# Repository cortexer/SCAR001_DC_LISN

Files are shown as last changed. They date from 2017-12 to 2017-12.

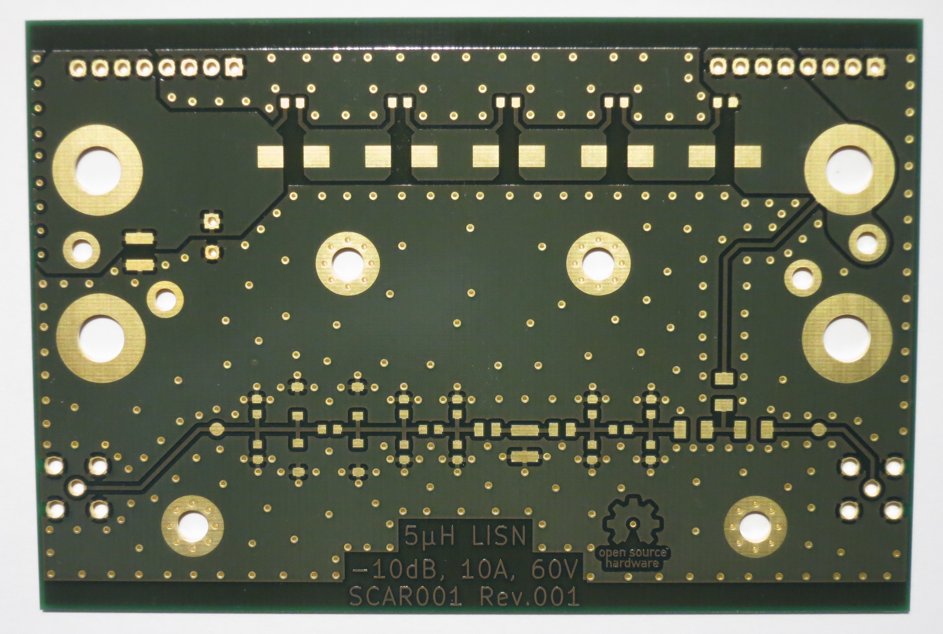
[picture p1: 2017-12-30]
06_Images/RawPCB.jpg

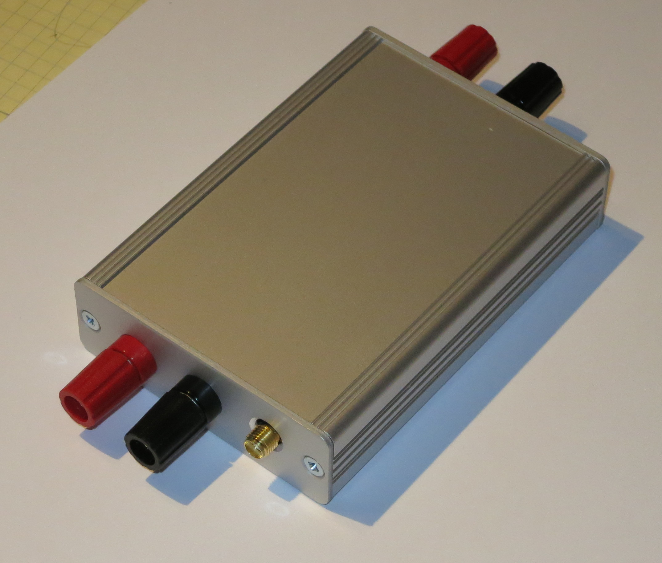
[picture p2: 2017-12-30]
06_Images/LISN_finished.jpg

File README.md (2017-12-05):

# SCAR001_DC_LISN
5µH DC LISN for conducted EMI measurements

This is a simple 5µH DC LISN design made in KiCad.
A "Line Impedance Stabilization Network" (LISN) is used for conducted EMC measurements.
It is a partial implementation of Linear Technology's DC2130A.
It features a -10dB attenuator and provides AC coupling to the spectrum analyzer using 50 ohm transmission lines
through an SMA connector.

It is a very simple design. For some more information look at the schematic.

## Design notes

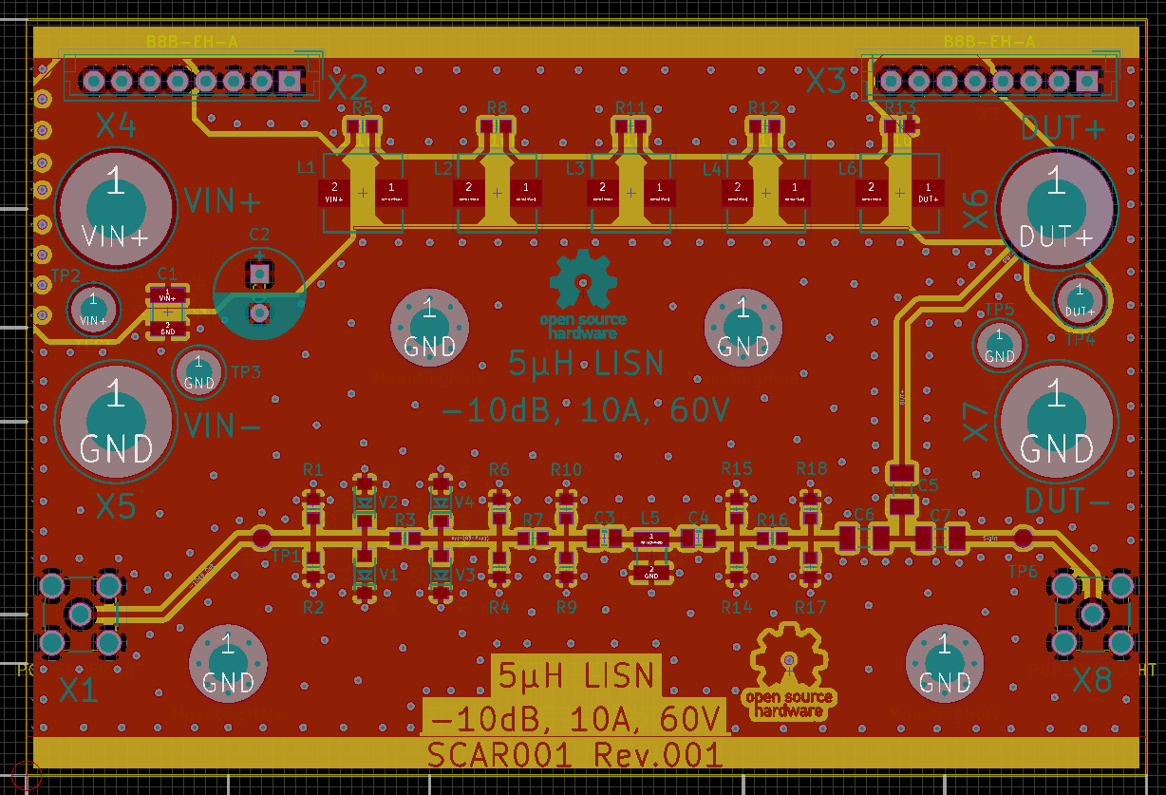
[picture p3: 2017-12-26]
05_Screenshots/Screenshot_Top.png

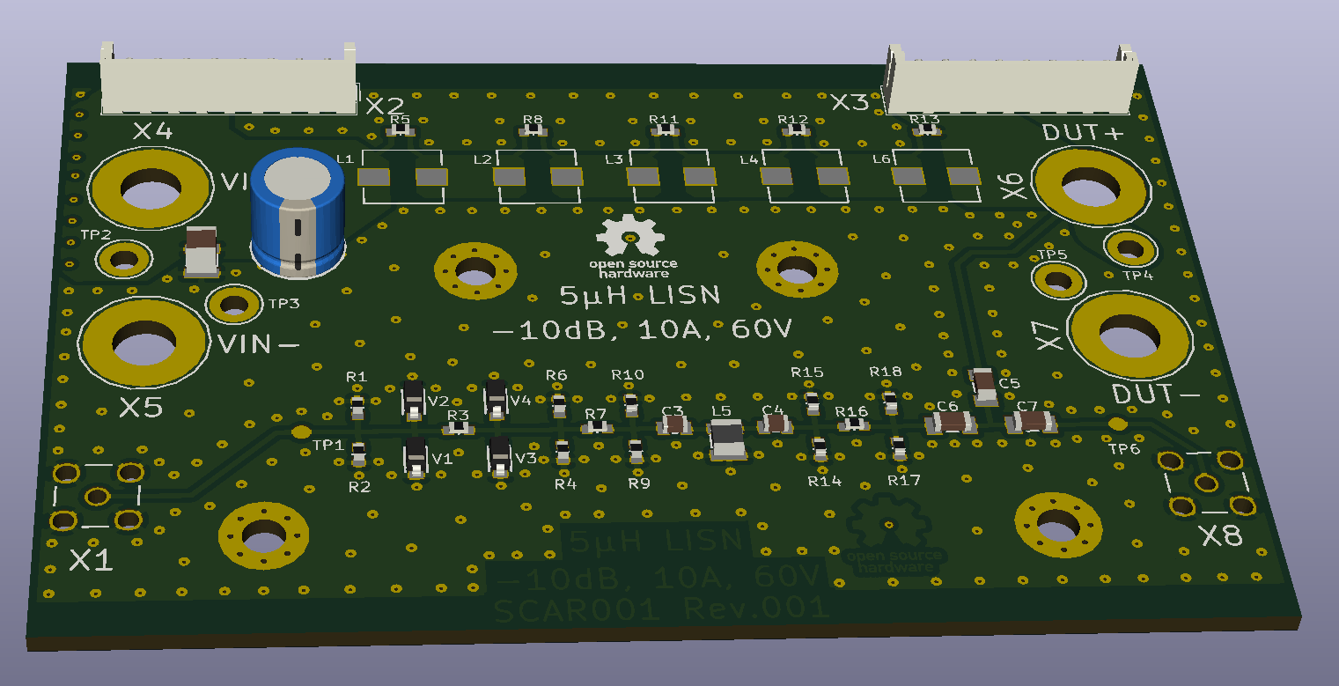
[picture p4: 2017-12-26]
05_Screenshots/Screenshot_3D.png

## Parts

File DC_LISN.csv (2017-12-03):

Source: | C:/m/Checkouts_HW/SCAR001_DC_LISN/DC_LISN.sch
Date: | 03.12.2017 22:20:55
Tool: | Eeschema 4.0.7
Generator: | C:/Program Files/KiCad/bin/scripting/plugins/bom_csv_grouped_by_value_with_fp.py
Component Count: | 53
Ref | Qnty | Value | Cmp name | Footprint | Description | Vendor
C1, | 1 | 4.7uF | C | MST_Lib:C_1210 | Unpolarized capacitor
C2, | 1 | 27uF | CP | MST_Lib:C_Alu_Radial_D8.0mm_P3.50mm | Polarised capacitor
C4, C3, | 2 | 470nF | C | MST_Lib:C_0805 | Unpolarized capacitor
C5, C6, C7, | 3 | 100nF | C | MST_Lib:C_1206 | Unpolarized capacitor
L1, L2, L3, L4, L6, | 5 | 1.1uH | L | MST_Lib:L_Wuerth_744314110 | Inductor
L5, | 1 | 1mH | L | MST_Lib:L_1210 | Inductor
M1, M2, M3, M4, | 4 | MountingHole | MountingHole | MST_Lib:M_MountingHole_3.5mm_Pad_Via | Mounting hole
R1, | 1 | 825R | R | MST_Lib:R_0603 | Resistor
R2, | 1 | 909R | R | MST_Lib:R_0603 | Resistor
R3, | 1 | 12.1R | R | MST_Lib:R_0603 | Resistor
R4, | 1 | 243R | R | MST_Lib:R_0603 | Resistor
R5, R8, R11, R12, R13, | 5 | 261R | R | MST_Lib:R_0603 | Resistor
R6, | 1 | 274R | R | MST_Lib:R_0603 | Resistor
R7, | 1 | 30.1R | R | MST_Lib:R_0603 | Resistor
R15, R14, R10, R9, | 4 | 432R | R | MST_Lib:R_0603 | Resistor
R16, | 1 | 18.2R | R | MST_Lib:R_0603 | Resistor
R17, | 1 | 562R | R | MST_Lib:R_0603 | Resistor
R18, | 1 | 619R | R | MST_Lib:R_0603 | Resistor
TP1, TP6, | 2 | TEST | TEST | MST_Lib:TP_1mm | Testpoint, connection for test equipment
TP2, TP3, TP4, TP5, | 4 | TEST | TEST | MST_Lib:TP_MillMax_2501 | Testpoint, connection for test equipment
V4, V3, V2, V1, | 4 | 1N4148W | D | MST_Lib:V_SOD-123 | Diode
X1, X8, | 2 | PCB.SMAFRA.HT | Conn_Coaxial | MST_Lib:X_SMA_THT_Jack_Straight_PCB.SMAFRA.HT | coaxial connector (BNC, SMA, SMB, SMC, Cinch/RCA, ...)
X2, X3, | 2 | B8B-EH-A | Conn_01x08 | MST_Lib:X_JST_EH_B08B-EH-A_08x2.50mm_Straight | Generic connector, single row, 01x08
X4, X5, X6, X7, | 4 | 575-4 | Conn_01x01 | MST_Lib:X_Keystone_575-4 | Generic connector, single row, 01x01

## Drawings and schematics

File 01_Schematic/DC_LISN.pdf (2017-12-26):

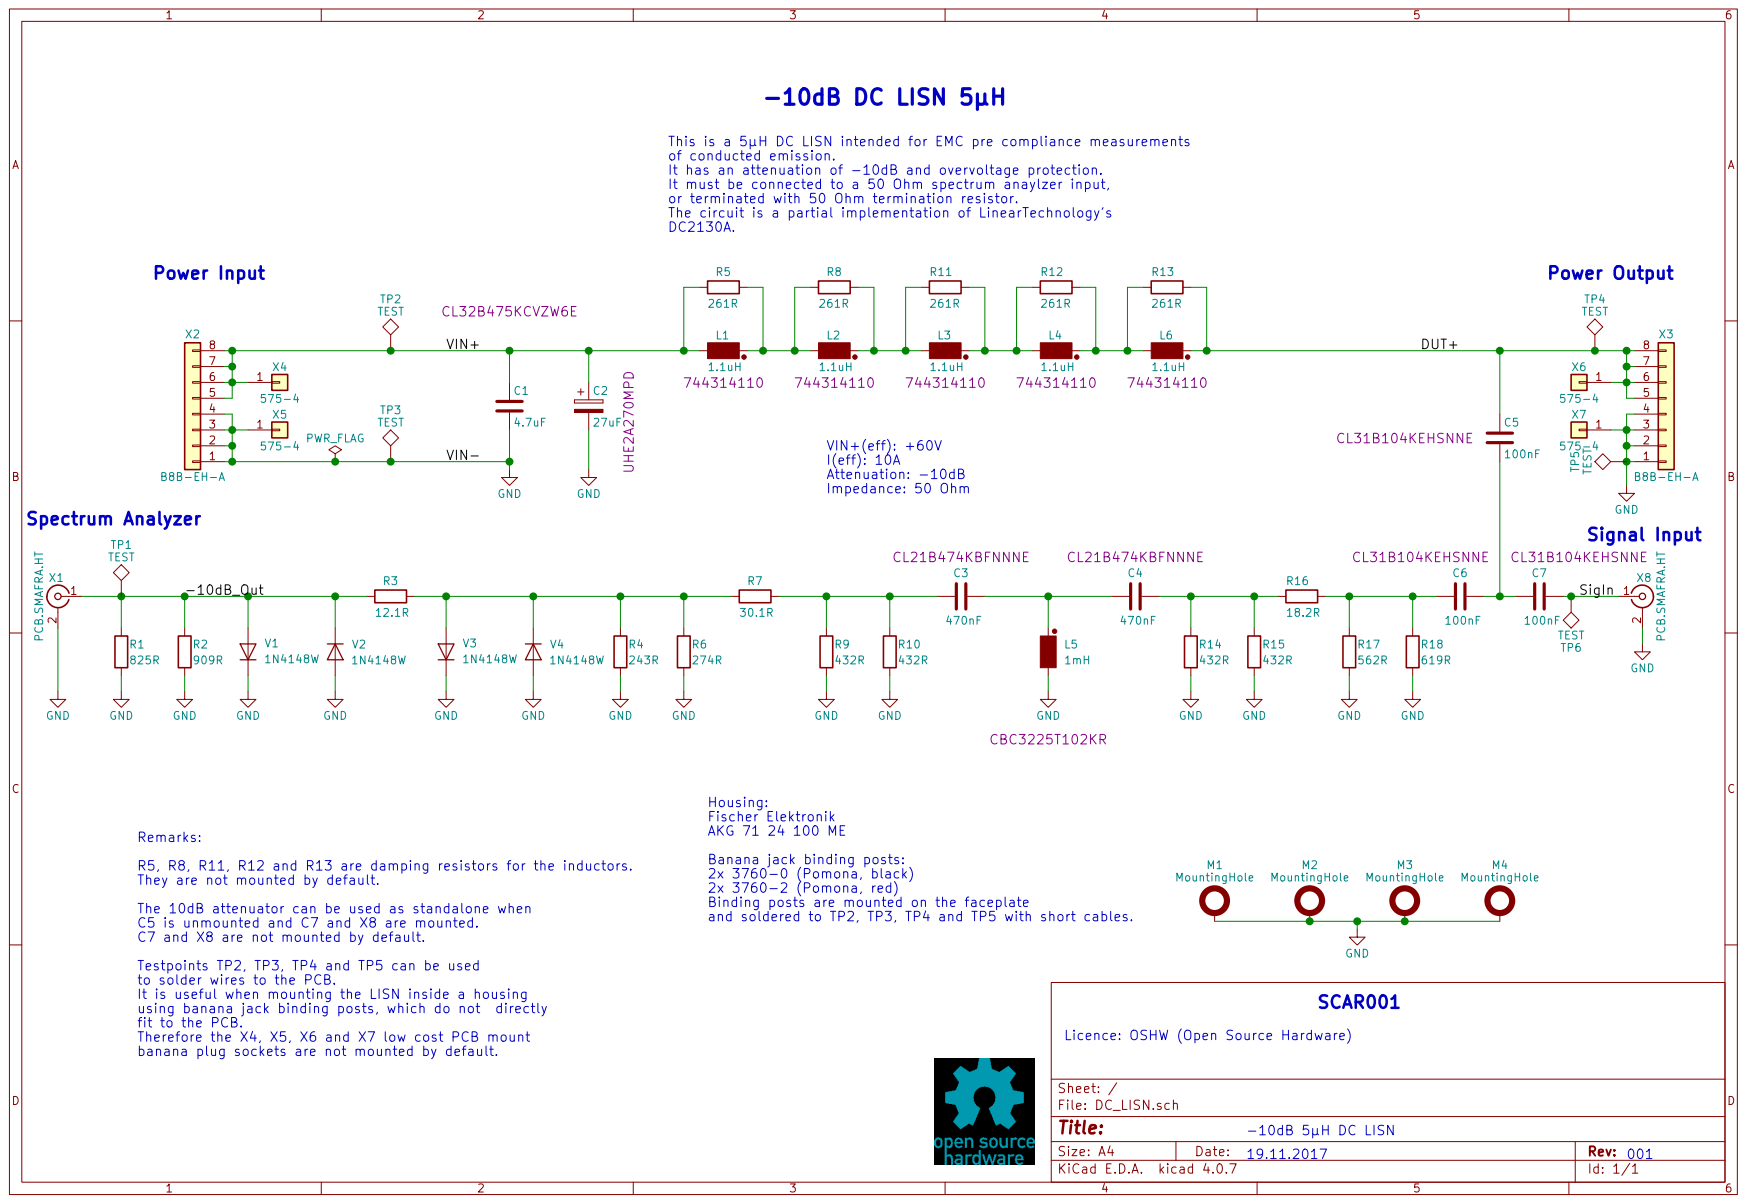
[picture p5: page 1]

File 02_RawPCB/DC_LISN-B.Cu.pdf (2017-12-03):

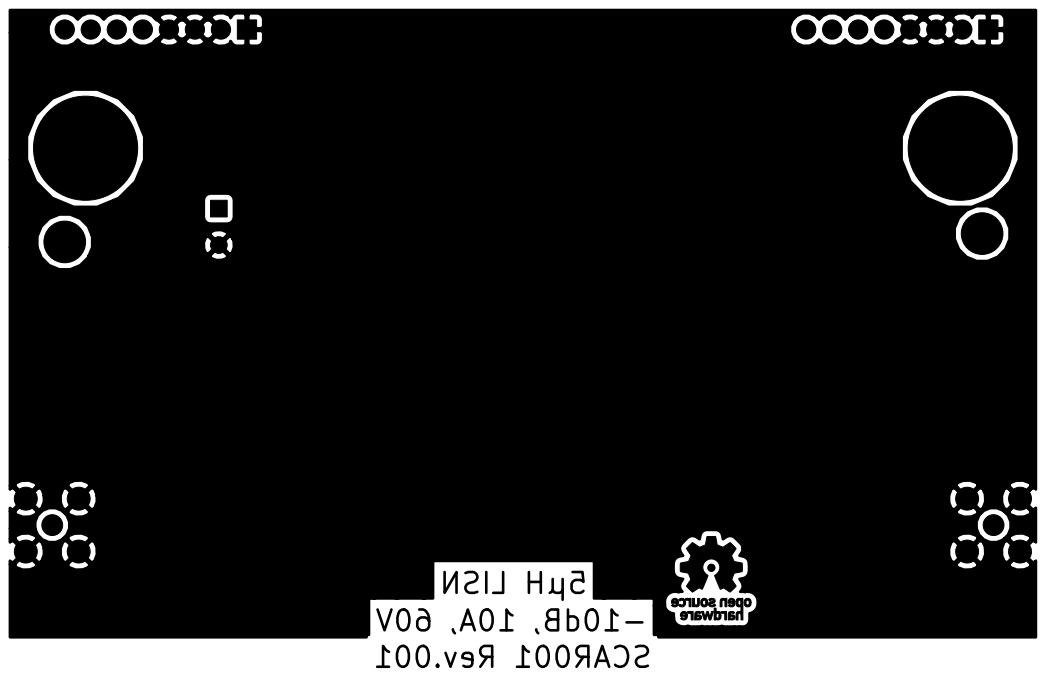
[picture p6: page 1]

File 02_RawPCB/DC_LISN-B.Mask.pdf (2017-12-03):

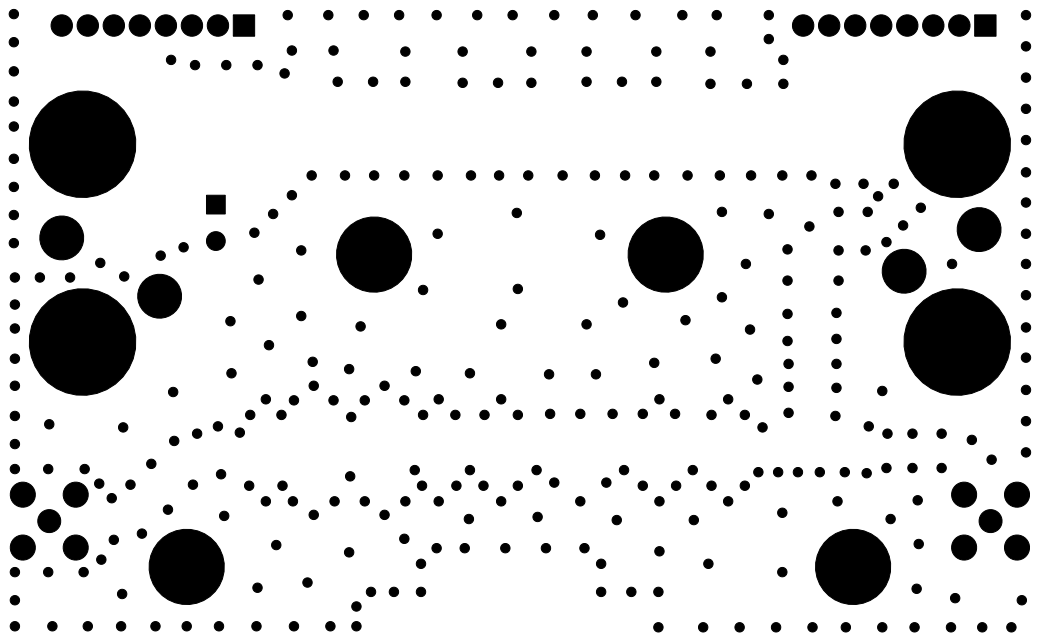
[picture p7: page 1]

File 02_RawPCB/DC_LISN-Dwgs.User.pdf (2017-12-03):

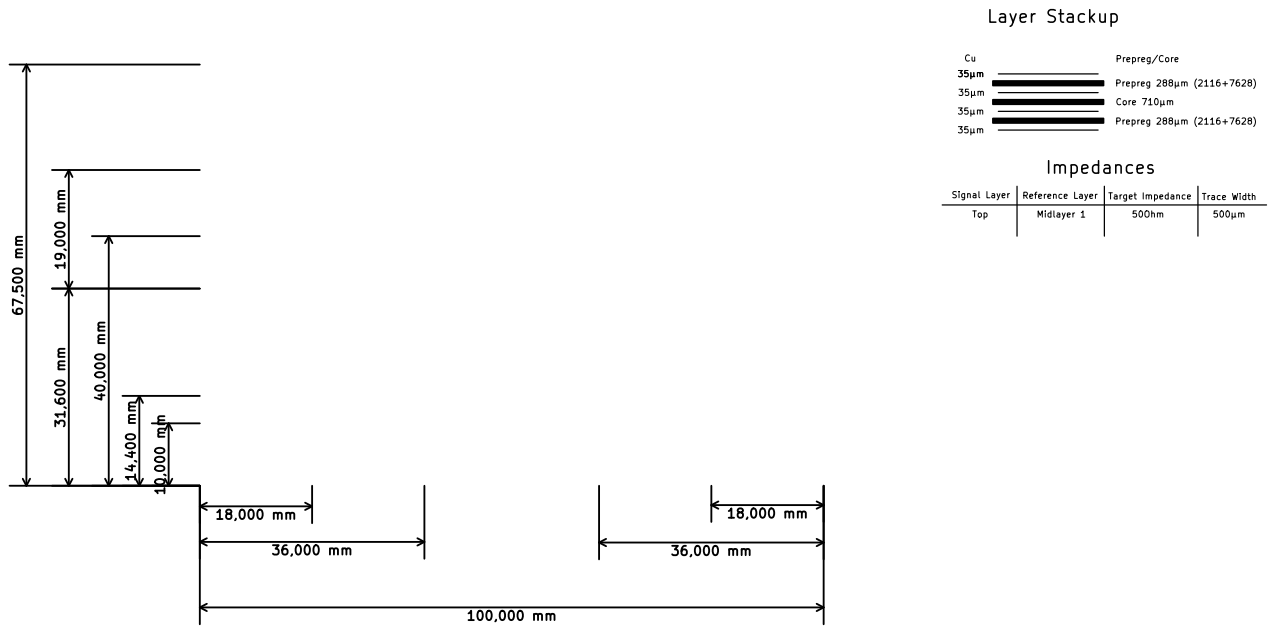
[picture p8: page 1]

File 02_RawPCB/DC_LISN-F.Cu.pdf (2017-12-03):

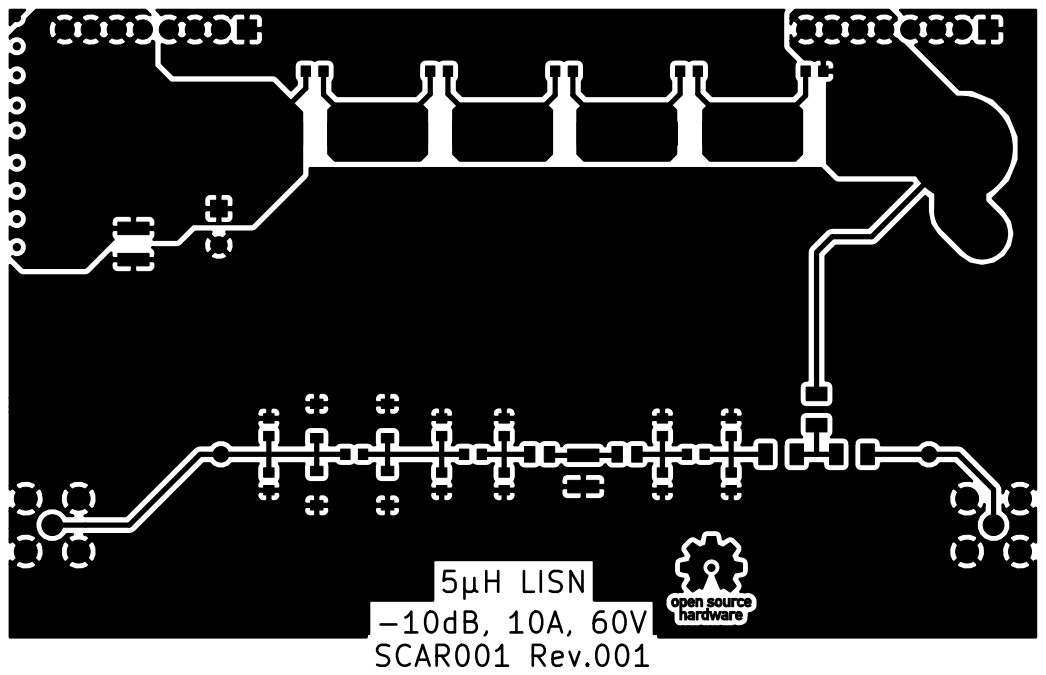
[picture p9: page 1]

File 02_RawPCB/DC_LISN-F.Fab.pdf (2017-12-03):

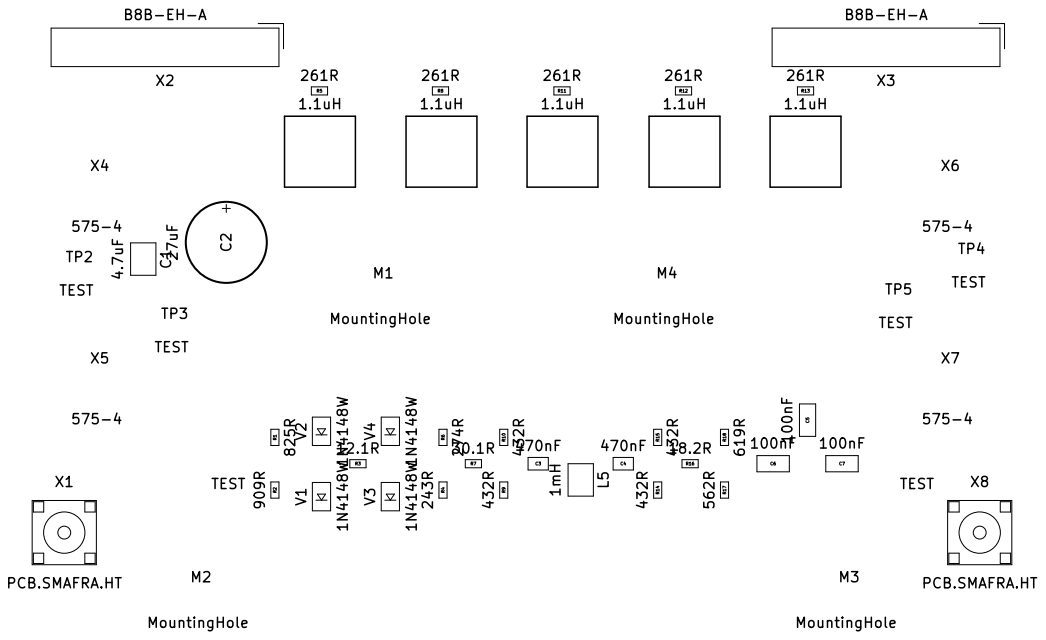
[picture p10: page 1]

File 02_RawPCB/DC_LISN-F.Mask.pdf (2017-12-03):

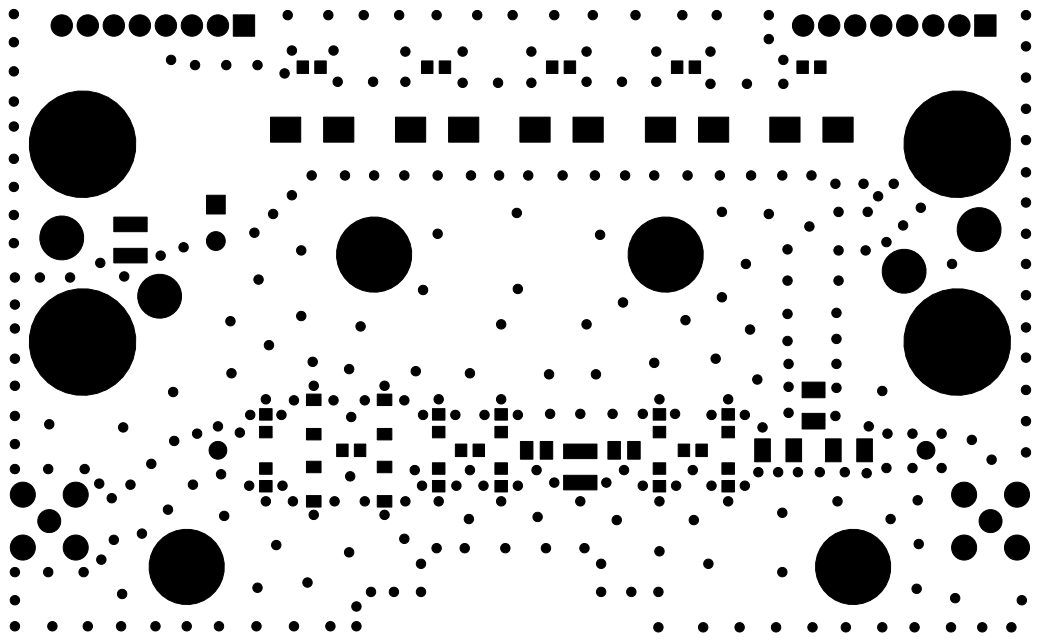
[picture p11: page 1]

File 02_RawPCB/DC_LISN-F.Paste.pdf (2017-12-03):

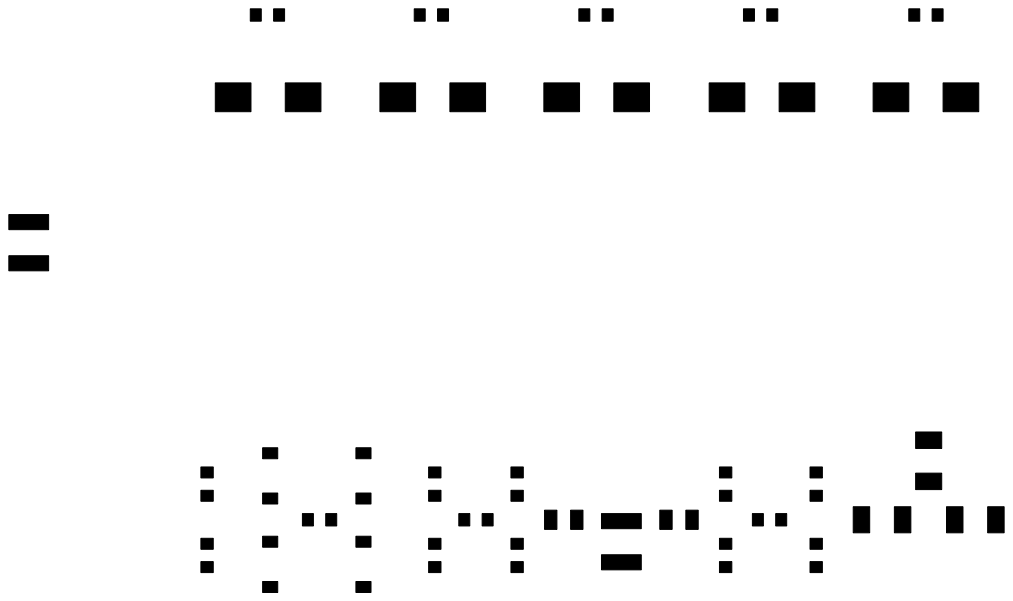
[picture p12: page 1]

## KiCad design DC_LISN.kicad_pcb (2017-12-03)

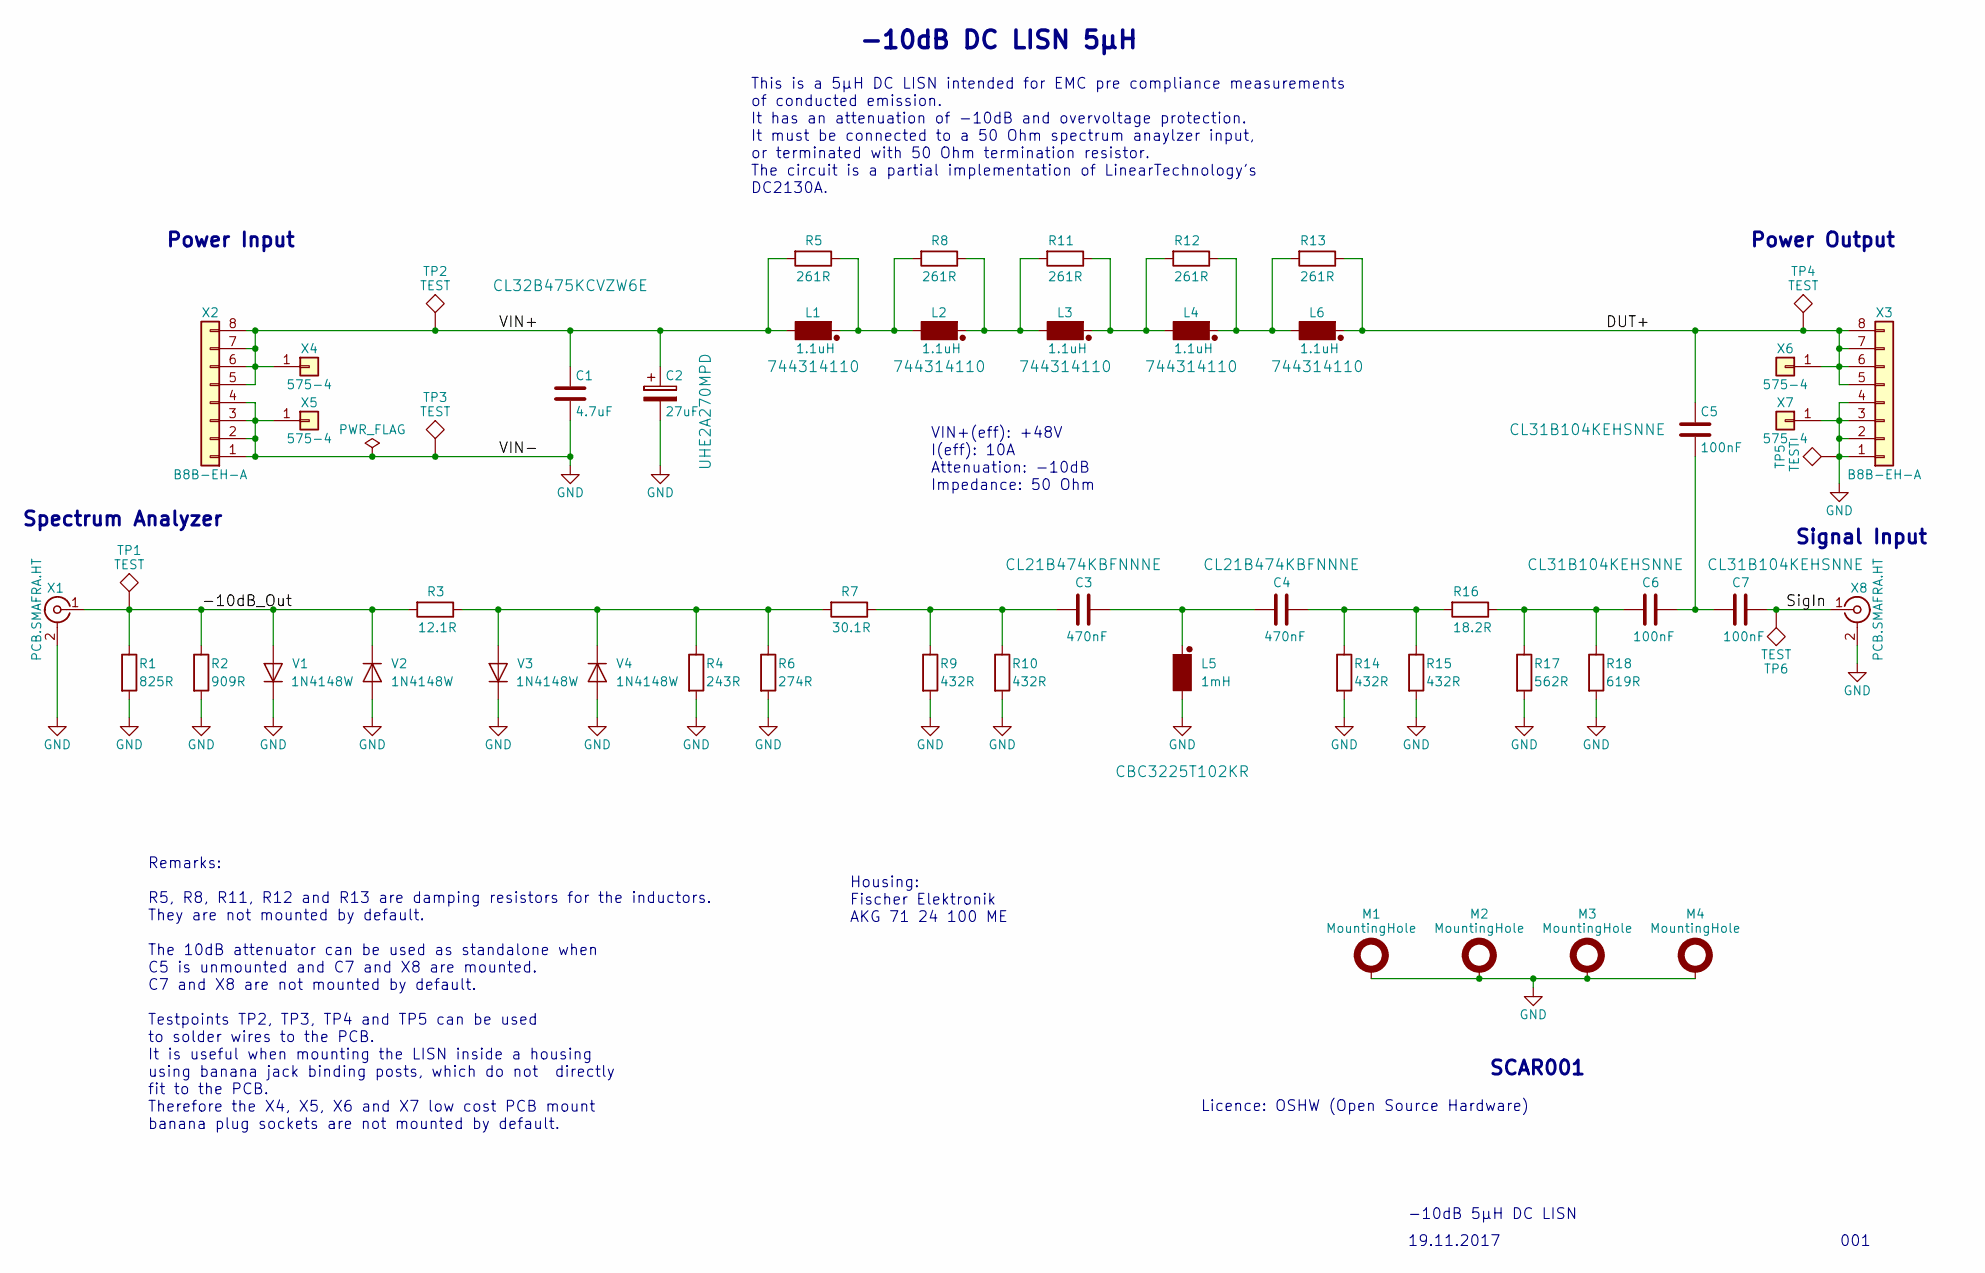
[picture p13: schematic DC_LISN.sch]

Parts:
C1: 4.7uF; C_1210
C2: 27uF; C_Alu_Radial_D8.0mm_P3.50mm
C3, C4: 470nF; C_0805
C5, C6, C7: 100nF; C_1206
L1, L2, L3, L4, L6: 1.1uH; L_Wuerth_744314110
L5: 1mH; L_1210
M1, M2, M3, M4: MountingHole; M_MountingHole_3.5mm_Pad_Via
R1: 825R; R_0603
R2: 909R; R_0603
R3: 12.1R; R_0603
R4: 243R; R_0603
R5, R8, R11, R12, R13: 261R; R_0603
R6: 274R; R_0603
R7: 30.1R; R_0603
R9, R10, R14, R15: 432R; R_0603
R16: 18.2R; R_0603
R17: 562R; R_0603
R18: 619R; R_0603
TP1, TP6: TEST; TP_1mm
TP2, TP3, TP4, TP5: TEST; TP_MillMax_2501
V1, V2, V3, V4: 1N4148W; V_SOD-123
X1, X8: PCB.SMAFRA.HT; X_SMA_THT_Jack_Straight_PCB.SMAFRA.HT
X2, X3: B8B-EH-A; X_JST_EH_B08B-EH-A_08x2.50mm_Straight
X4, X5, X6, X7: 575-4; X_Keystone_575-4

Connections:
/-10dB_Out: R1.1, R2.1, R3.2, TP1.1, V1.2 (A), V2.1 (K), X1.1 (In)
/DUT+: C5.1, L6.1, R13.1, TP4.1, X3.5, X3.6, X3.7, X3.8, X6.1
/SigIn: C7.1, TP6.1, X8.1 (In)
/VIN+: C1.1, C2.1, L1.2, R5.2, TP2.1, X2.5, X2.6, X2.7, X2.8, X4.1
GND: C1.2, C2.2, L5.2, M1.1, M2.1, M3.1, M4.1, R1.2, R2.2, R4.2, R6.2, R9.2, R10.2, R14.2, R15.2, R17.2, R18.2, TP3.1, TP5.1, V1.1 (K), V2.2 (A), V3.1 (K), V4.2 (A), X1.2 (Ext), X2.1, X2.2, X2.3, X2.4, X3.1, X3.2, X3.3, X3.4, X5.1, X7.1, X8.2 (Ext)
unnamed: C3.1, C4.2, L5.1
unnamed: C3.2, R7.1, R9.1, R10.1
unnamed: C4.1, R14.1, R15.1, R16.2
unnamed: C5.2, C6.1, C7.2
unnamed: C6.2, R16.1, R17.1, R18.1
unnamed: L1.1, L2.2, R5.1, R8.2
unnamed: L2.1, L3.2, R8.1, R11.2
unnamed: L3.1, L4.2, R11.1, R12.2
unnamed: L4.1, L6.2, R12.1, R13.2
unnamed: R3.1, R4.1, R6.1, R7.2, V3.2 (A), V4.1 (K)

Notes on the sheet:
-10dB DC LISN 5µH
This is a 5µH DC LISN intended for EMC pre compliance measurements of conducted emission. It has an attenuation of -10dB and overvoltage protection. It must be connected to a 50 Ohm spectrum anaylzer input, or terminated with 50 Ohm termination resistor. The circuit is a partial implementation of L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
VIN+(eff): +48V I(eff): 10A Attenuation: -10dB Impedance: 50 Ohm
19.11.2017
001
-10dB 5µH DC LISN
Licence: OSHW (Open Source Hardware)
Power Input
Spectrum Analyzer
Power Output
Housing: Fischer Elektronik AKG 71 24 100 ME
SCAR001
Remarks: R5, R8, R11, R12 and R13 are damping resistors for the inductors. They are not mounted by default. The 10dB attenuator can be used as standalone when C5 is unmounted and C7 and X8 are mounted. C7 and X8 are not mounted by default. Testpoints TP2, TP3, TP4 and TP5 can be used to solder wire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
Signal Input

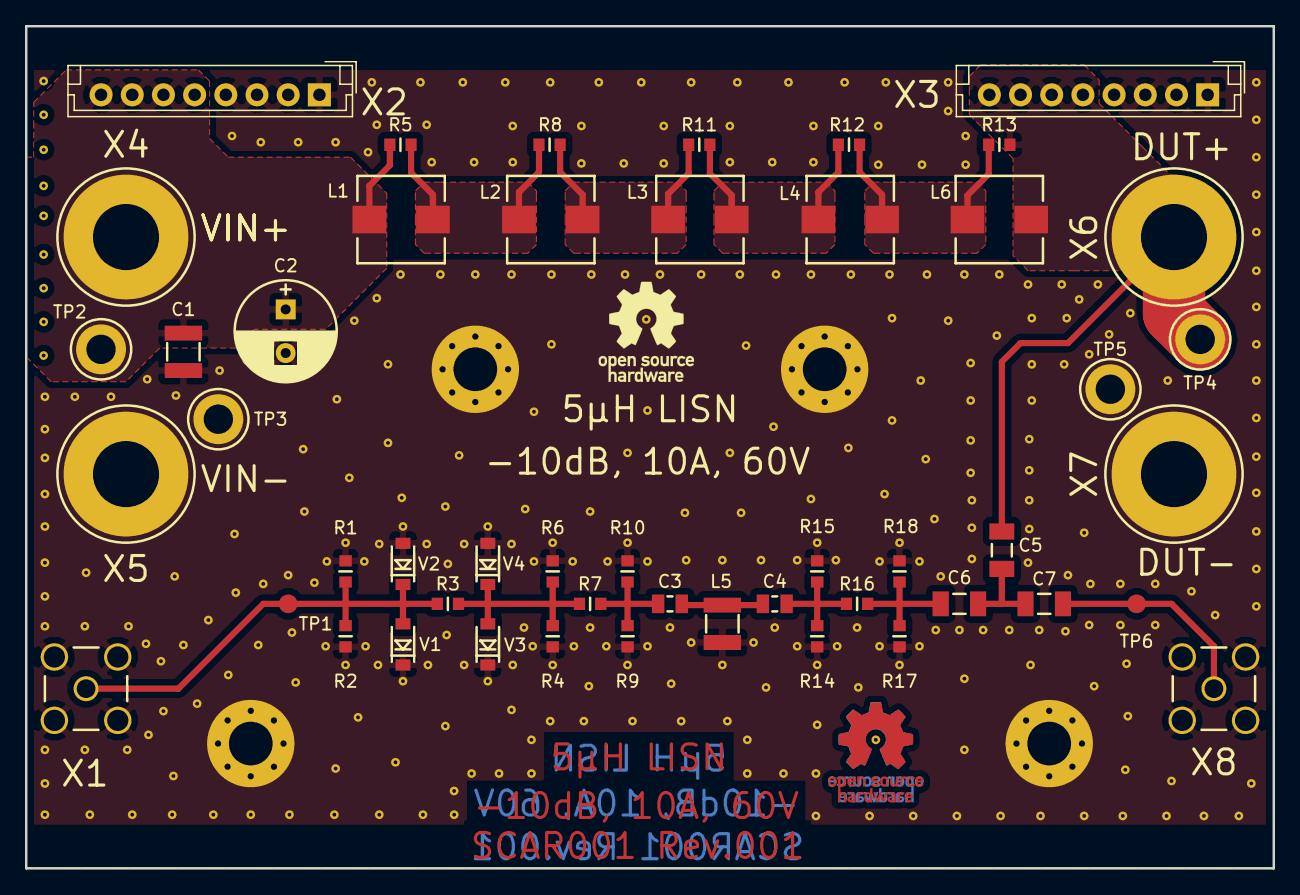
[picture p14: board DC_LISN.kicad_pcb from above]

Board: 4 copper layers, 100.0 x 67.5 mm, 53 parts (0 on the bottom side), 15 nets.

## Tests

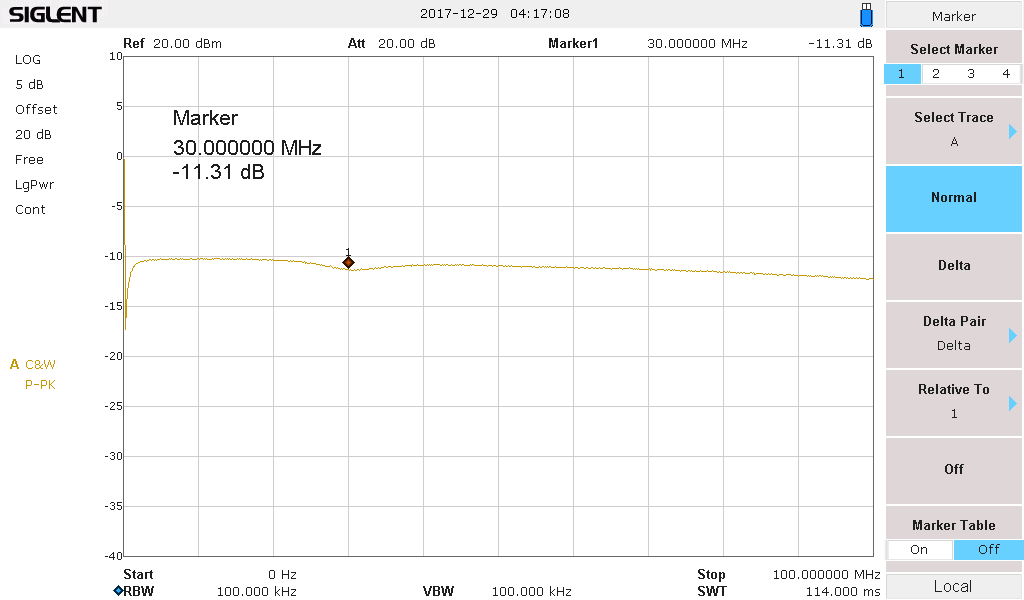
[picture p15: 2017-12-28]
07_Measurements/Unit2/PNG2.png

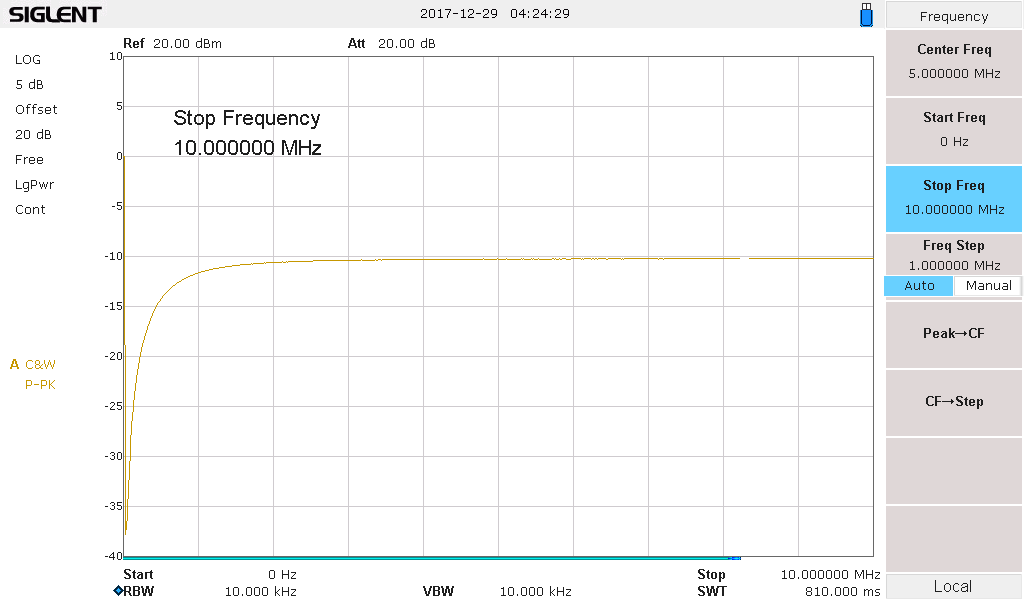
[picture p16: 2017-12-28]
07_Measurements/Unit2/PNG6.png

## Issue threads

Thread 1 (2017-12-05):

BOM: Component BOM is missing

cortexer, 2017-12-05:
No real BOM exists yet. I have not yet found out how KiCad handles components which are present within the layout but should not be mounted.
Also how I can incorporate the manufacturer and order number of the components into a simple BOM.
Probably a customized BOM script is needed.

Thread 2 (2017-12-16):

Mechanical collision: Enclosure and banana sockets.

cortexer, 2017-12-16:
If you mount the Keystone 575-4 banana sockets, the PCB will not fit into the enclosure any more.
If you want to use the enclosure just don't mount X4, X5, X6 and X7.

cortexer, 2017-12-26:
When using the proposed enclosure,
you will want to use the banana binding posts which are mounted on the enclosure faceplate.

Closed 2017-12-26.

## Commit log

2017-12-02 Schematic and Layout: Added initial schematic and layout. This is a 5µH DC LISN to be used for conducted EMI measurements.
    [DC_LISN.kicad_pcb, DC_LISN.sch]
2017-12-03 Licensing: Changed to OSHW Changed licensing to open source hardware. Added an additional signal input for use as standalone attenuator.
    [DC_LISN.kicad_pcb, DC_LISN.sch]
2017-12-03 Schematic: Added comments
    [DC_LISN.kicad_pcb, DC_LISN.sch]
2017-12-03 Schematic: Improved comments
    [DC_LISN.kicad_pcb, DC_LISN.sch]
2017-12-03 Layout: Documented Stackup and Impedances
    [DC_LISN.kicad_pcb]
2017-12-03 Gerber: Generated fabrication data. Also printed schematic and updated BOM.
    [DC_LISN-B.Cu.gbr, DC_LISN-B.Fab.gbr, DC_LISN-B.Mask.gbr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]
2017-12-26 Schematic: Comments updated Added binding post order numbers to comments.
    [DC_LISN.sch]
2017-12-30 Images: Added Image Added images of final LISN and raw PCB.
